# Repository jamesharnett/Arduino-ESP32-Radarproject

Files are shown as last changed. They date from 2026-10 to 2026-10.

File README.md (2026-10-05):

# Arduino ESP32 mmWave Radar Project
-------------------------------------------------------------------------------------------------------
Safety & disclaimer

This is a hobby project, shared as-is for anyone who wants to build their own version.
A few things to know before you do:

LiPo batteries: incorrect wiring, reverse polarity, or physical damage to a
LiPo cell can cause fire. Double-check polarity yourself before powering anything
on, use a charging module rated for the cell you're using, and never leave a
charging LiPo unattended.
RF hardware: the RD-03D and any radio modules in this project operate
according to their respective regulatory approvals (e.g. CE) for their intended
region — verify this applies to your location before use.
No warranty: this repository (firmware, wiring diagrams, enclosures, and this
README) is provided without any warranty, express or implied. Verify every
connection yourself before applying power — don't assume the diagrams here are
free of mistakes.
Use at your own risk: building and operating this project is entirely your
own responsibility. The author assumes no liability for damage, injury, or loss
resulting from building or using this project.

If you spot an error in the docs, wiring, or code, please open an issue — corrections
are welcome.
-------------------------------------------------------------------------------------------------------

A wireless 24GHz mmWave motion tracking system. A standalone radar node reports detected
targets over Wi-Fi to a separate display unit — so the radar and the screen don't have to
be in the same place.

v22 v21

## How it works

The radar module talks to an Arduino GIGA R1 via a Wi-Fi hotspot using a Seeed XIAO
ESP32-S3 as the transmitter. Because the link is wireless, the radar node can be placed
anywhere as a standalone motion detector, independent of where the display sits.

## Features

- Multi-target tracking (up to 3 people simultaneously, RD-03D built-in algorithm)
- 8 m rated detection range (expect 5–7 m indoors)
- Live radar-style visualization on the GIGA Display Shield
- Distance-reactive tracker sound (passive piezo buzzer, tempo and pitch scale with
  the closest target's distance) — mute toggle built into the touchscreen
- LED battery level indicators on both battery packs
- Battery powered on both ends, USB-C rechargeable

## Known limitations

- The RD-03D is a **Doppler-based** radar — it only detects *moving* targets. People
  standing still are not detected.
- Works best stationary. It can detect people while the sensor itself is moving, but
  accuracy drops significantly.
- Can detect motion through thin doors/walls, but range is severely reduced — a
  consequence of 24GHz wave physics, not a firmware limitation.
- **Boot order matters**: always power on the GIGA R1 first and let it fully initialize
  before powering the radar node. Otherwise the Wi-Fi connection will not be established.

## Bill of materials

| Qty | Part |
|---|---|
| 1 | Arduino GIGA R1 |
| 1 | Arduino GIGA Display Shield |
| 1 | Seeed Studio XIAO ESP32-S3 |
| 1 | RD-03D radar module (Ai-Thinker) |
| 2 | Toggle switch |
| 2 | MT3608 step-up converter |
| 1 | 3.7V LiPo, 1160100 (≥5000mAh) — GIGA side |
| 1 | 3.7V LiPo, 602560 (~1300mAh) — radar side |
| 2 | BW4056 USB-C charging module |
| 1 | Passive piezo buzzer module (VCC/GND/Signal, tracker sound, GIGA side) |
| 2 | Mini Battery Level Indicator, 1S Li-ion — [ElectroPeak BAT-03-086](https://electropeak.com/mini-battery-level-indicator-1s-li-ion), one per LiPo |
| 4 | Magnets |
| — | Wires, M3 heat-set inserts, M3x10mm screws, 3D printer, glue, tape |

## Wiring

circuit diagram v2

**Power (GIGA side):** LiPo (5000mAh) → BW4056 charging module → toggle switch →
step-up converter set to 7–7.5V → GIGA `VIN`. Do not set it to 6V: that is the
bottom of the GIGA's 6–24V input range and the board browns out as the cell
discharges. Alternatively feed 5V into the GIGA's USB-C port from a 5V boost or
power-bank module and skip `VIN` altogether.

**Power (radar side):** LiPo (1300mAh) → BW4056 charging module → toggle switch →
XIAO `BAT+`/`BAT-` (on the back of the board), **directly**. A second branch from
the switched battery rail feeds the step-up converter set to 5V, which powers
**only the RD-03D**.

Never connect the 5V step-up output to `BAT+`: the BAT pads are the cell
terminals of the XIAO's 1S charger (4.2V maximum), and a cell behind a boost
converter cannot be charged by the XIAO. With the cell on the BAT pads the XIAO's
USB-C also charges it (100mA, slow); never charge through the BW4056 and the XIAO
at the same time.

### XIAO ESP32-S3 ↔ RD-03D (transmitter)

| RD-03D pin | XIAO pin | Notes |
|---|---|---|
| TX | D0 (GPIO1) | UART1 RX |
| RX | D1 (GPIO2) | UART1 TX |
| VCC | — | 5V from the step-up converter output (see *Power (radar side)* above), not from the XIAO's `5V` pin |
| GND | GND | |

CAUTION: When charging the battery, set the POWER button to OFF. The same applies when the microcontroller is connected via USB-C. 

Baud rate: 256000. Do **not** use D6/D7 (GPIO43/44) — reserved for USB-Serial (UART0).

Antennas: neither the XIAO ESP32-S3 nor the GIGA R1 WiFi has an on-board antenna.
Plug in the u.FL antenna that ships with each board, and route the XIAO's away from
the LiPo and the magnets, or the Wi-Fi link will only work over a few metres.

### Wi-Fi link
### Arduino Giga R1 ↔ (receiver)
| | Value |
|---|---|
| Mode | GIGA R1 hosts an access point, XIAO connects as client |
| SSID | `RadarNet` |
| Password | `radar12345` |
| UDP port | 4210 |
| GIGA IP | 192.168.3.1 (default of the Arduino Mbed core; the sketch never sets an address and the XIAO uses the DHCP gateway, so nothing depends on this value) |

### Tracker sound (buzzer)

| Buzzer | GIGA R1 |
|---|---|
| VCC | 3V3 (GIGA pins are not 5V tolerant and many 3-pin buzzer modules pull the signal line up to VCC) |
| Signal (I/O) | D9 |
| GND | GND |

Must be a **passive** piezo buzzer, not active — an active buzzer has its own
oscillator and only turns on/off, ignoring the frequency argument the code sends it.

Behavior: silent when no target is detected. Once a target appears, it emits short
(70ms) pings whose repeat rate and pitch both scale with the distance to the closest
detected target — pings speed up and rise in pitch as someone gets closer (900ms /
700Hz at ~8m down to 120ms / 1800Hz at ≤30cm). A mute toggle button is drawn directly
on the touchscreen; tapping it silences the buzzer without affecting the radar
visualization.

### Battery level indicators

Two [ElectroPeak Mini Battery Level Indicator (1S Li-ion)](https://electropeak.com/mini-battery-level-indicator-1s-li-ion)
boards, one per LiPo pack. These are standalone analog modules (built-in comparator,
±1% accuracy) — no microcontroller pin or firmware involved. Wire each board directly
across its own battery's `+`/`-` terminals (in parallel with the existing BW4056 /
step-up wiring, not in series):

| Indicator LEDs lit | Charge level |
|---|---|
| 4 | 100% |
| 3 | 75% |
| 2 | 50% |
| 1 | 25% |

Board size is tiny (5 × 9.5mm) — tuck it wherever it fits in the enclosure near the
battery leads.

## Firmware

Open `Firmware 1.1/rd03d_xiao_s3_sender/rd03d_xiao_s3_sender.ino` and flash it to the
XIAO ESP32-S3, then open `Firmware 1.1/rd03d_giga_receiver/rd03d_giga_receiver.ino` and
flash it to the GIGA R1 — both via Arduino IDE. (The Arduino IDE requires the sketch
folder to carry the sketch's own name, which is why the folders are not suffixed.)

**Board packages:**
- `esp32` by Espressif (3.x) — board "XIAO_ESP32S3", *USB CDC On Boot: Enabled*
- `Arduino Mbed OS GIGA Boards` (4.x) — board "Arduino GIGA R1 WiFi". If the GIGA has never
  run Wi-Fi, flash *File → Examples → STM32H747_System → WiFiFirmwareUpdater* once first.

**Required libraries:**
- `Arduino_GigaDisplay_GFX` (GIGA — display rendering; depends on `Adafruit GFX Library`)
- `Arduino_GigaDisplayTouch` (GIGA — touch input)
- `WiFi` / `WiFiUdp` (both boards, built into their respective cores)

## Enclosures

Four 3D-printable parts are included in `CAD files/` (binary STL; bounding boxes
measured from the files):

| File | Bounding box (mm) | Part |
|---|---|---|
| `CAD files/body display.stl` | 34 × 105 × 113 | display body (GIGA + shield + 1160100 LiPo) |
| `CAD files/top display.stl` | 8 × 85 × 111 | display lid |
| `CAD files/top radarmodule.stl` | 47 × 31 × 87 | radar node body |
| `CAD files/bottom radarmodule.stl` | 47 × 6 × 67 | radar node base plate |

## Build photos (older ones, without the battery indicator and buzzer)

building pictures

## License

MIT — see [LICENSE](LICENSE).

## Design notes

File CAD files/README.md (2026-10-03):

# Enclosures

## v1 parts (original author, print-ready)

Binary STL exports from Autodesk Fusion; bounding boxes measured from the files.
They fit the **Level 1** radar node and the GIGA display.

| File | Bounding box (mm) | Holds |
|---|---|---|
| `body display.stl` | 34 × 105 × 113 | GIGA R1 + Display Shield + 1160100 LiPo |
| `top display.stl` | 8 × 85 × 111 | display lid |
| `top radarmodule.stl` | 47 × 31 × 87 | XIAO + RD-03D + 602560 LiPo |
| `bottom radarmodule.stl` | 47 × 6 × 67 | radar node base plate |

Triangle counts are low (208–1088), so curved features print faceted. The GIGA
board is 101.5 mm long inside a 105 mm body: check the fit in your slicer.

## Level 2 sensor node (DRAFT, unverified)

`level2_sensor_node.scad` is a parametric OpenSCAD model for the radar + LIDAR
node: XIAO ESP32-S3, RD-03D lying horizontally behind a 1.2 mm front window,
MT3608, TP4056/BW4056, a 103450 pouch cell, toggle switch and LED indicator
inside a 78 × 100 × 32 mm box, with the LD19 bolted on top of the lid where it
has a clear 360° view. `level2_sensor_node_base.stl` and `level2_sensor_node_lid.stl`
are rendered from the defaults; `level2_sensor_node_preview.png` shows the assembly.

**It was designed from datasheet dimensions, not from measured parts, and has
never been printed.** Before you commit filament:

1. Measure your modules and put the numbers into the parameters at the top of
   the `.scad` file (`rd03d`, `xiao`, `mt3608`, `tp4056`, `cell`, `switch_d`).
2. The LD19 mounting-hole pattern (`ld19_holes`, four holes on a 22 mm square) is
   a **guess**. Measure the base of your LD19, or print the lid alone first and
   drill to fit.
3. The RD-03D needs a plastic window under 2 mm and no metal within 20 mm; the
   model thins the front wall to `rd03d_window_t` over the module. Keep the cell
   and the switch away from that face.
4. A ≥ 3000 mAh cell (recommended for Level 2 runtime) is larger than the
   103450 pocket; set `cell` and raise `box_d` accordingly.
5. Tape the XIAO's flex antenna under the lid in the marked slot, not next to
   the cell, and plug it in before closing the box.

Render with:

```bash
openscad -D 'part="base"' -o level2_sensor_node_base.stl level2_sensor_node.scad
openscad -D 'part="lid"'  -o level2_sensor_node_lid.stl  level2_sensor_node.scad
```

Open the file in OpenSCAD with `part="assembly"` to see the lid, the LD19
silhouette and the RD-03D position together.

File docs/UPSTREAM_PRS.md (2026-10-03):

# Fixes prepared for the upstream repositories

The audit behind the RadarLink rewrite found defects in the original v1 code
and README. They are prepared as small, independent branches in this fork so
each can be opened as its own pull request against the author's repositories.
The branches are based on `main`, which is identical to the upstream `main`
(commit `c41c875`).

| Branch in this fork | Target repository | Files | Summary |
|---|---|---|---|
| `fix/readme-wiring-and-facts` | `Stevee87/Arduino-ESP32-Radarproject` | `README.md` | 5 V boost into XIAO `BAT+` corrected (cell on BAT pads, boost feeds only the RD-03D); GIGA VIN 7–7.5 V or USB-C instead of 6 V; antennas; buzzer on 3V3; AP address 192.168.3.1; firmware paths; real enclosure files and sizes; BW4056 naming; board packages and Adafruit GFX dependency; duplicate caution; typo |
| `fix/wifiudp-include-case` | `Stevee87/Arduino-ESP32-Radarproject` | receiver `.ino` | `#include <WiFiUDP.h>` → `<WiFiUdp.h>`; the sketch did not compile on Linux |
| `fix/giga-receiver-robustness` | `Stevee87/Arduino-ESP32-Radarproject` | receiver `.ino` | check `WiFi.beginAP()` and show the failure on screen; drain all queued UDP datagrams per loop instead of one; `fb[12]` overflow → `fb[16]`; "R4" labels renamed |
| `fix/xiao-transmitter-nonblocking` | `Stevee87/Arduino-ESP32-Radarproject` | transmitter `.ino` | non-blocking Wi-Fi connect with retry instead of a 20 s block and `ESP.restart()`; the 650 ms radar re-configuration every 60 s turned into a timed step sequence; clustering keeps the speed with the larger magnitude |
| `fix/receiver-packet-format` in `jamesharnett/Radar-project-Uconsole` | `Stevee87/Radar-project-Uconsole` | `Firmware/uconsole_radar_receiver.py` | the Python receiver unpacked 29 of the 32 packet bytes and corrupted targets 2 and 3 (`"hhhB"` → `"hhhBx"` per target). The same change also exists as a `git am` patch on this fork's `fix/radar-project-uconsole-struct-format` branch, which is now redundant |

Each code branch was compiled for its board (esp32 core 3.3.12 for the XIAO,
Arduino Mbed OS GIGA Boards 4.6.0 for the GIGA) before it was pushed. The
receiver robustness branch only builds on Linux once the include-name fix is
also merged; the two are kept separate so the one-line fix can land on its own.

## Opening the pull requests

From the fork on GitHub: *Pull requests → New → compare across forks*, base
`Stevee87/Arduino-ESP32-Radarproject:main`, head `<fork>:<branch>`. The commit
message of each branch is written to serve as the PR description.

For the `Radar-project-Uconsole` fix, open the pull request from
`jamesharnett/Radar-project-Uconsole:fix/receiver-packet-format` against
`Stevee87/Radar-project-Uconsole:main`.

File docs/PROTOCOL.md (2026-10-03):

# RadarLink v1 — UDP wire protocol

Every node in the system speaks one protocol on one UDP port. The sensor node
(ESP32-S3 with the RD-03D radar and the optional LD19 LIDAR) is the Wi-Fi access
point and the only sender of measurement data. Receivers (the Arduino GIGA R1
display and the uConsole viewer) announce themselves with a `HELLO` once per
second and the sensor node unicasts every data packet to each receiver that has
said hello within the last five seconds. There is no broadcast: the original
author measured unreliable delivery of broadcast frames under LIDAR load, and
unicast frames are acknowledged and retransmitted by the Wi-Fi layer.

The canonical machine-readable definition is
`Firmware/sensor_node_esp32s3/radar_protocol.h`. The copy in
`Firmware/giga_display/` must stay byte-identical (`tools/check_protocol_sync.py`),
and `uconsole/radar_protocol.py` is the Python mirror, verified against the C
header by `uconsole/tests/test_protocol.py`.

## Conventions

* UDP port **4210** for everything, in both directions.
* All multi-byte integers are **little-endian**.
* Every field is written byte by byte. No struct is ever sent raw, so compiler
  padding can never change the format (the v1 firmware had exactly that trap:
  an unpacked 7-byte struct became 8 bytes on the wire and a third-party decoder
  written for 29 bytes misread targets 2 and 3).
* No datagram is longer than **508 bytes**, because that is the receive buffer
  of the Arduino Mbed `WiFiUDP` implementation on the GIGA R1. Anything longer
  would be truncated there without an error.
* Receivers accept data only from the sensor node's address (the Wi-Fi gateway)
  and drop packets whose sequence number is not newer than the last one seen for
  that type. Wi-Fi security is WPA2 with the pre-shared key in `config.h`; change
  it before deploying.

## Common header (8 bytes)

| Offset | Size | Field | Value |
|---:|-----:|---|---|
| 0 | 4 | `magic` | `0x314C4452`, the ASCII bytes `52 44 4C 31` ("RDL1") |
| 4 | 1 | `type` | see below |
| 5 | 1 | `version` | `1` |
| 6 | 2 | `seq` | per-type sequence counter of the sender, wraps at 65535 |

| Type | Name | Direction | Rate |
|-----:|---|---|---|
| `0x01` | `RADAR`  | sensor node → receivers | one per RD-03D frame, about 10 to 20 per second |
| `0x02` | `LIDAR`  | sensor node → receivers | about 47 per second with the LD19 at 10 Hz |
| `0x03` | `STATUS` | sensor node → receivers | 1 per second |
| `0x10` | `HELLO`  | receiver → sensor node  | 1 per second |

## RADAR (type 0x01), 36 bytes

| Offset | Size | Field |
|---:|-----:|---|
| 8  | 4 | `frame_count`, RD-03D frames parsed since boot |
| 12 | 24 | three target slots of 8 bytes each (see below) |

Each slot:

| Offset in slot | Size | Field |
|---:|-----:|---|
| 0 | 2 | `x_mm`, `int16`, lateral position, positive to the right of the radar's forward axis |
| 2 | 2 | `y_mm`, `int16`, forward distance |
| 4 | 2 | `speed_cm_s`, `int16`, radial speed with the RD-03D's sign convention |
| 6 | 1 | `valid`, `1` if the slot holds a target, otherwise `0` and the other fields are `0` |
| 7 | 1 | reserved, `0` |

The slot index is stable while the RD-03D keeps tracking the same person, which
is why receivers colour targets by slot. The sensor node has already applied the
range gate (100 mm to 8000 mm), the sentinel-speed filter (`0`, `±248`, `±256`
cm/s are noise in the RD-03D firmware) and the clustering of two returns closer
than 1 m into one target.

## LIDAR (type 0x02), 12 + 5·N bytes, N ≤ 96

| Offset | Size | Field |
|---:|-----:|---|
| 8  | 2 | `scan_speed_deg_s`, motor speed reported by the LD19 |
| 10 | 1 | `count` N, number of points that follow, at most 96 |
| 11 | 1 | `flags`, reserved, `0` |
| 12 | 5·N | points |

Each point:

| Offset in point | Size | Field |
|---:|-----:|---|
| 0 | 2 | `angle_cdeg`, `uint16`, 0 to 35999, hundredths of a degree, increasing clockwise seen from above, in the LD19's own reference |
| 2 | 2 | `dist_mm`, `uint16`, never `0` (points without a return are dropped at the sensor node) |
| 4 | 1 | `intensity` |

A packet carries up to eight LD19 frames of twelve points. The receivers apply
the mounting offset `LIDAR_ANGLE_OFFSET_DEG` from their own configuration, so
the sensor node never needs recalibrating for a different display.

## STATUS (type 0x03), 32 bytes

| Offset | Size | Field |
|---:|-----:|---|
| 8  | 4 | `uptime_ms` |
| 12 | 2 | `radar_fps`, RD-03D frames parsed in the last second |
| 14 | 2 | `lidar_fps`, LD19 frames parsed in the last second |
| 16 | 2 | `lidar_pps`, LIDAR points sent in the last second |
| 18 | 1 | `subscribers`, receivers currently registered |
| 19 | 1 | `flags`: bit 0 radar frames seen in the last second, bit 1 lidar frames seen, bit 2 radar multi-target mode configured, bit 3 firmware built with LIDAR support |
| 20 | 4 | `radar_bad_frames`, cumulative frames with a bad tail |
| 24 | 4 | `lidar_crc_errors`, cumulative |
| 28 | 4 | reserved |

Receivers show these numbers in their HUD. They make the difference between
"the radar is not wired" and "the Wi-Fi link is down" visible at a glance.

## HELLO (type 0x10), 12 bytes

| Offset | Size | Field |
|---:|-----:|---|
| 8  | 1 | `receiver_kind`: `1` GIGA display, `2` uConsole, `3` other |
| 9  | 1 | `wants` bitmask: bit 0 radar, bit 1 lidar, bit 2 status |
| 10 | 2 | reserved |

The sensor node records the source address and port of each `HELLO` and sends
to that address until no `HELLO` has arrived for 5 s. Up to four receivers are
served at once. A receiver that is only interested in radar can clear bit 1 and
save the LIDAR bandwidth.

## Timing constants

| Constant | Value | Meaning |
|---|---:|---|
| `RL_HELLO_INTERVAL_MS` | 1000 | receivers send `HELLO` this often |
| `RL_SUBSCRIBER_TIMEOUT_MS` | 5000 | sensor node forgets a silent receiver |
| `RL_LINK_TIMEOUT_MS` | 3000 | receiver declares the link dead and clears the screen |

## Worked example

A radar packet with one target at x = −782 mm, y = 1713 mm, −16 cm/s in slot 0,
sequence 7, frame 1234:

```
52 44 4C 31  01 01  07 00   | magic "RDL1", type RADAR, version 1, seq 7
D2 04 00 00                  | frame_count 1234
F2 FC  B1 06  F0 FF  01 00   | slot 0: x=-782 y=1713 speed=-16 valid=1 pad
00 00  00 00  00 00  00 00   | slot 1 empty
00 00  00 00  00 00  00 00   | slot 2 empty
```

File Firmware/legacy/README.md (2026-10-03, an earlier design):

# Legacy v1 firmware (reference only)

These are the original two sketches by Sudo_solder, kept so the first-generation
build (GIGA R1 as access point, XIAO as client, 32-byte packed-struct packets on
UDP 4210) can still be flashed and compared against. They are **not** compatible
with the current sensor node, display or uConsole viewer, which use the RadarLink
protocol in `docs/PROTOCOL.md`.

The only change made here is the `WiFiUdp.h` include name in the receiver, which
the Mbed core ships in that case and which failed to compile on Linux as `WiFiUDP.h`.

Known issues in this code, found in the audit that led to the rewrite:

* the transmitter unicasts to the Wi-Fi gateway only, so a second viewer gets nothing;
* the GIGA reads one UDP datagram per loop while each dot erase re-walks the whole
  sector with ~125k trig calls, so the display lags under load and never catches up;
* a blocking 20 s Wi-Fi connect followed by `ESP.restart()` reboot-loops the XIAO;
* a 650 ms blocking re-configuration of the radar every 60 s;
* `WiFi.beginAP()` failure is never checked, so a missing Wi-Fi firmware looks like a boot-order problem;
* the README's `192.168.4.1` is wrong for this core (the AP is `192.168.3.1`);
* `char fb[12]` overflows after 100 million frames (about 116 days).

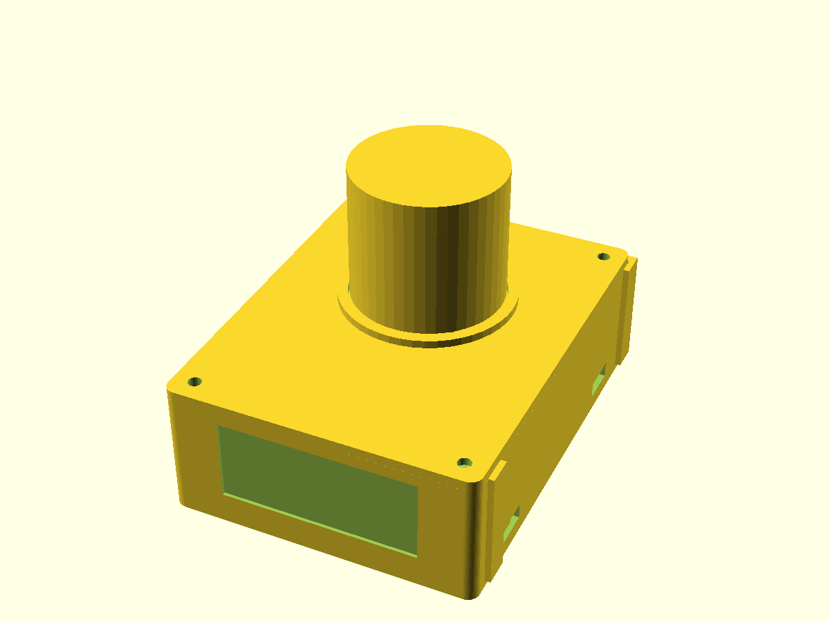
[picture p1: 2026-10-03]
CAD files/level2_sensor_node_preview.png

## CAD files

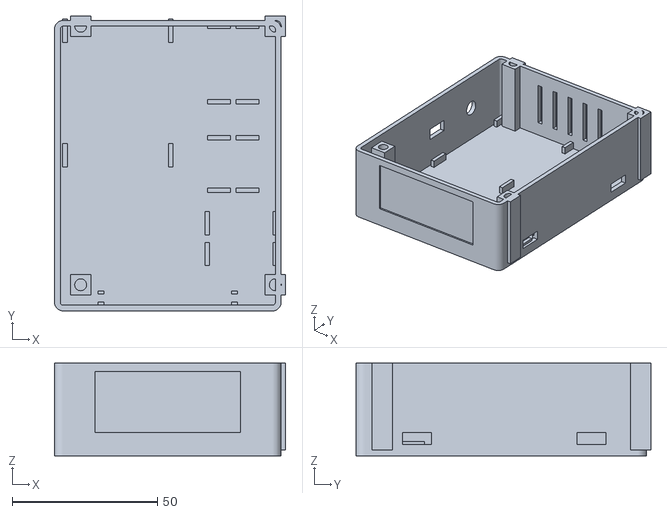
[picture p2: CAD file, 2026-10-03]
CAD files/level2_sensor_node_base.stl
79.5 x 101.5 x 32.0

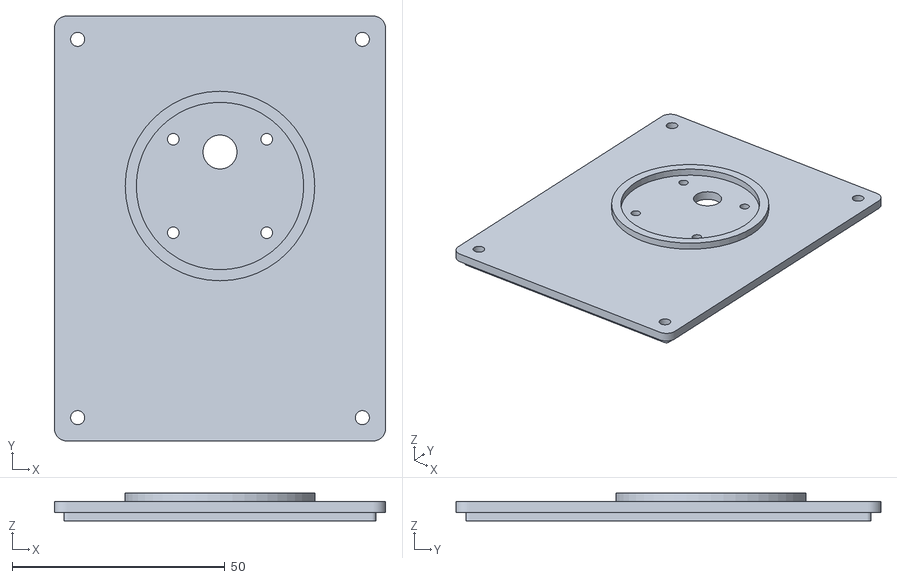
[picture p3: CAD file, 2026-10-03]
CAD files/level2_sensor_node_lid.stl
78.0 x 100.0 x 6.49

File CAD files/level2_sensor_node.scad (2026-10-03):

// level2_sensor_node.scad — RadarLink Level 2 sensor node enclosure (DRAFT, unverified)
//
// Holds: Seeed XIAO ESP32-S3, Ai-Thinker RD-03D (horizontal, behind a thin front
// window), MT3608 boost module, TP4056/BW4056 USB-C charger, a pouch cell, a
// toggle switch and a 1S LED indicator, with the LDROBOT LD19 LIDAR mounted on
// top of the lid where it has a clear 360-degree view.
//
// THIS IS A DRAFT DESIGNED FROM DATASHEET NUMBERS, NOT FROM MEASURED PARTS.
// Before printing in earnest: measure every module you actually own and put the
// numbers into the parameters below, print only the lid first to check the LD19
// hole pattern (ld19_holes is a guess), and check the RD-03D window thickness
// (keep it under 2 mm, no metal within 20 mm of the module's face).
//
// Render:  openscad -D 'part="base"' -o level2_base.stl level2_sensor_node.scad
//          openscad -D 'part="lid"'  -o level2_lid.stl  level2_sensor_node.scad
// Preview: part="assembly"
//
// Axes: x = width (left/right), y = depth (front at -y), z = up. The RD-03D
// looks towards -y; mount the LD19 so its connector points to +y, then set the
// receivers' LIDAR_ANGLE_OFFSET_DEG from the calibration in docs/TESTING.md.
//
// SPDX-License-Identifier: MIT

part = "assembly";          // "base" | "lid" | "assembly"

/* ------------------------------------------------------------ parameters */
wall      = 2.0;            // side wall thickness
floor_t   = 2.0;
lid_t     = 2.5;
corner_r  = 3.0;
clear     = 0.4;            // clearance added around parts

// components (mm) — MEASURE YOURS
rd03d     = [44.0, 2.0, 15.0];  // PCB width, thickness (with antenna face), height; mounted horizontally
rd03d_window_t = 1.2;           // front window thickness in front of the radar
xiao      = [21.0, 17.8, 4.0];  // PCB x, y, height incl. components (USB-C adds 1.3 mm on one side)
mt3608    = [36.0, 17.0, 12.0]; // boost module incl. trimmer
tp4056    = [28.0, 17.0, 6.0];  // USB-C charger module
cell      = [34.0, 50.0, 10.5]; // pouch cell; 103450 = 2000 mAh. 3000 mAh (e.g. 606090: 60x90x6) needs box_d >= 110
switch_d  = 6.2;                // toggle switch hole
indicator = [9.5, 5.0];         // 1S 4-LED indicator window (w, h)
ld19_dia  = 38.6;               // LD19 body diameter
ld19_h    = 34.8;               // LD19 height above its base
ld19_holes = [[-11.0, -11.0], [11.0, -11.0], [-11.0, 11.0], [11.0, 11.0]];  // GUESS: measure the LD19 base
ld19_hole_d = 2.7;              // M2.5 clearance
ld19_cable_d = 8.0;

// layout
box_w = 74;                     // internal width
box_d = 96;                     // internal depth
box_h = 30;                     // internal height (components lie flat)
insert_d = 4.1;                 // heat-set insert hole for M3
insert_h = 6.0;
post     = 7.0;                 // corner post size

$fn = 48;

/* --------------------------------------------------------------- helpers */
module rrect(w, d, h, r) {
    hull() for (sx = [-1, 1], sy = [-1, 1])
        translate([sx * (w / 2 - r), sy * (d / 2 - r), 0]) cylinder(r = r, h = h);
}

module pocket(size, z = floor_t, rail = 1.6, rail_h = 3.0) {
    // four short rails that locate a PCB of `size` on the floor without screws
    s = [size[0] + 2 * clear, size[1] + 2 * clear];
    for (sx = [-1, 1], sy = [-1, 1])
        translate([sx * (s[0] / 2 + rail / 2), sy * (s[1] / 2 - 4), z])
            cube([rail, 8, rail_h], center = false);
}

ow = box_w + 2 * wall;
od = box_d + 2 * wall;
oh = box_h + floor_t;

/* ------------------------------------------------------------------ base */
module base() {
    difference() {
        union() {
            rrect(ow, od, oh, corner_r);
        }
        // cavity
        translate([0, 0, floor_t]) rrect(box_w, box_d, box_h + 1, corner_r - wall > 0.5 ? corner_r - wall : 0.5);
        // RD-03D window: thin the front wall to rd03d_window_t over the module face
        translate([-(rd03d[0] + 6) / 2, -od / 2 - 0.01, floor_t + 6])
            cube([rd03d[0] + 6, wall - rd03d_window_t + 0.01, rd03d[2] + 6]);
        // TP4056 USB-C on the right wall, near the back
        translate([ow / 2 - wall - 0.01, box_d / 2 - 12 - 10, floor_t + 2]) cube([wall + 0.02, 10, 4]);
        // XIAO USB-C on the right wall, near the front (programming)
        translate([ow / 2 - wall - 0.01, -box_d / 2 + 14, floor_t + 2]) cube([wall + 0.02, 10, 4]);
        // toggle switch on the left wall
        translate([-ow / 2 - 0.01, box_d / 2 - 20, floor_t + box_h / 2]) rotate([0, 90, 0]) cylinder(d = switch_d, h = wall + 0.02);
        // indicator window on the left wall
        translate([-ow / 2 - 0.01, 0, floor_t + box_h / 2 - indicator[1] / 2]) cube([wall + 0.02, indicator[0], indicator[1]]);
        // vents on the back wall
        for (i = [-2 : 2]) translate([i * 8 - 1, od / 2 - wall - 0.01, floor_t + 6]) cube([2, wall + 0.02, box_h - 12]);
    }
    // corner posts with heat-set insert holes
    for (sx = [-1, 1], sy = [-1, 1]) difference() {
        translate([sx * (box_w / 2 - post / 2), sy * (box_d / 2 - post / 2), floor_t]) cube([post, post, box_h], center = false);
        translate([sx * (box_w / 2 - post / 2) + post / 2, sy * (box_d / 2 - post / 2) + post / 2, floor_t + box_h - insert_h])
            cylinder(d = insert_d, h = insert_h + 0.01);
    }
    // RD-03D cradle: two slots the module slides into, face against the window
    for (sx = [-1, 1]) translate([sx * (rd03d[0] / 2 + 1.0) - 1.0, -box_d / 2, floor_t])
        difference() {
            cube([2.0, rd03d[1] + 2 * clear + 2, rd03d[2] + 8]);
            translate([-0.01, 1.0, 2]) cube([2.02, rd03d[1] + 2 * clear, rd03d[2] + 7]);
        }
    // component pockets (flat on the floor)
    translate([-box_w / 2 + cell[0] / 2 + 2, box_d / 2 - cell[1] / 2 - 2, 0]) pocket(cell);
    translate([box_w / 2 - mt3608[1] / 2 - 2, box_d / 2 - mt3608[0] / 2 - 2, 0]) rotate([0, 0, 90]) pocket(mt3608);
    translate([box_w / 2 - tp4056[1] / 2 - 2, 6, 0]) rotate([0, 0, 90]) pocket(tp4056);
    translate([box_w / 2 - xiao[0] / 2 - 2, -box_d / 2 + xiao[1] / 2 + 10, 0]) pocket(xiao);
}

/* ------------------------------------------------------------------- lid */
module lid() {
    difference() {
        union() {
            rrect(ow, od, lid_t, corner_r);
            // inner lip
            translate([0, 0, -2]) difference() {
                rrect(box_w - 0.6, box_d - 0.6, 2.01, corner_r - wall > 0.5 ? corner_r - wall : 0.5);
                translate([0, 0, -0.01]) rrect(box_w - 0.6 - 2 * 1.6, box_d - 0.6 - 2 * 1.6, 2.03, 1);
            }
            // LD19 seat ring
            translate([0, 10, lid_t - 0.01]) difference() {
                cylinder(d = ld19_dia + 6, h = 2);
                translate([0, 0, -0.01]) cylinder(d = ld19_dia + 2 * clear, h = 2.02);
            }
        }
        // lid screws into the corner posts
        for (sx = [-1, 1], sy = [-1, 1])
            translate([sx * (box_w / 2 - post / 2), sy * (box_d / 2 - post / 2), -3]) cylinder(d = 3.3, h = lid_t + 6);
        // LD19 mounting holes and cable pass-through
        for (h = ld19_holes) translate([h[0], 10 + h[1], -3]) cylinder(d = ld19_hole_d, h = lid_t + 6);
        translate([0, 10 + 8, -3]) cylinder(d = ld19_cable_d, h = lid_t + 6);
        // antenna slot: the XIAO's flex antenna is taped under the lid, front-right, away from the cell
        translate([box_w / 2 - 14, -box_d / 2 + 4, -0.01]) cube([12, 30, 0.6]);
    }
}

module ld19_ghost() {
    color("silver", 0.4) translate([0, 10, oh + lid_t + 2]) cylinder(d = ld19_dia, h = ld19_h);
}

/* --------------------------------------------------------------- output */
if (part == "base") base();
else if (part == "lid") translate([0, 0, 0]) lid();
else {
    base();
    translate([0, 0, oh + 0.01]) lid();
    ld19_ghost();
    color("green", 0.5) translate([-rd03d[0] / 2, -box_d / 2 + 1.5, floor_t + 2]) cube(rd03d);
}

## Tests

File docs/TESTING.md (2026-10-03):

# Bring-up, testing and calibration

Work through this in order the first time. Every stage has an expected output,
so a radar wiring fault, a LIDAR fault and a Wi-Fi fault each look different.

## 0. Bench test the software without hardware

```bash
cd uconsole
python3 -m unittest discover -s tests            # 19 tests: protocol bytes vs the C header, state logic
python3 fake_sensor_node.py &                    # simulated sensor node on UDP 4210
python3 radar_viewer.py --node 127.0.0.1 --windowed
```

You should see a 6 × 4 m rectangular room outline with a gap (a "doorway") and
one or two walkers in the radar sector, `DATA OK` in the HUD and roughly
`rx 70/s`. Quit with ESC, stop the fake node with `kill %1`.

Parser tests for the firmware run on your PC too:

```bash
g++ -std=c++11 -Wall -Wextra -Werror -I Firmware/sensor_node_esp32s3 Firmware/tests/host/test_parsers.cpp -o /tmp/t && /tmp/t
```

## 1. Sensor node on USB power, radar only

Battery switch **off**, `ENABLE_LIDAR 0` for this step if you like, XIAO on USB,
serial monitor at 115200 baud. Expected:

```
RadarLink sensor node — RD-03D + LD19
radar UART1 rx=1 tx=2 @256000 | lidar UART2 rx=3 tx=4 @230400
[wifi] AP "RadarSystem" up on channel 6, IP 192.168.4.1, UDP port 4210
[boot] ready; waiting for receivers to say HELLO
[radar] multi-target mode configured
[stat] up=2s ap=up sta=0 subs=0 | radar fps=20 bytes=1234 bad=0 cfg=1 reconf=0 | lidar fps=0 pps=0 bytes=0 crc=0 speed=0 | heap=...
```

With the RD-03D powered from the boost converter (trimmed to 5.0 V first):

| What you see | Meaning |
|---|---|
| `radar fps=10..20 bad=0`, `bytes` growing | radar wired and configured. Normal. |
| `bytes` growing, `fps=0`, `bad` growing | framing wrong: wrong baud (must be 256000) or a swapped TX/RX pair that still receives garbage |
| `bytes=0` | no data at all: RD-03D not powered (needs 5 V), TX not on D0, or GND missing |
| `reconf` incrementing every 5 s | radar silent for 5 s each time; the node re-sends the mode command. Check the 5 V rail with a meter under load |

The LED blinks briefly every 0.5 s while no receiver is subscribed and every
2 s once one is.

## 2. Add the LD19

Connect the LD19 (Tx → D2, P5V from the boost, GND common, PWM open). The motor
spins up within a second. Expected in `[stat]`:

```
lidar fps=370..380 pps=3500..4500 crc=0 speed=3500..3700
```

| What you see | Meaning |
|---|---|
| `fps≈375 crc=0` | good. `pps` is lower than 4500 when part of the room is beyond 12 m or absorbs the laser |
| `bytes` growing, `fps=0`, `crc` growing | wrong baud (must be 230400) or noise on the line |
| `bytes=0` | LD19 TX not on D2, or no power. Listen for the motor |
| `crc` growing slowly with `fps≈370` | occasional corrupt frames: supply ripple or a long unshielded lead. Add the 220 µF + 10 µF at the sensors |

## 3. GIGA display

Serial monitor at 115200. Expected:

```
RadarLink GIGA display starting
[wifi] connecting to RadarSystem
[wifi] connected, IP 192.168.4.2, sensor node 192.168.4.1, RSSI -45
[stat] link=up data=ok rx/s=70 total=140 drop=0 foreign=0 fps=15 | node radar_fps=20 lidar_fps=375 subs=1
```

The screen shows the plot once joined; `WIFI OK`, `DATA OK` and the node's
counters appear in the top-left HUD. On the sensor node you will see
`[subs] + 192.168.4.2:4210 kind=1 wants=0x07 (1 total)` and `[wifi] station joined`.

| What you see | Meaning |
|---|---|
| `connect failed, status 4` repeating, screen says "last attempt failed (code 4)" | the Mbed core returns 4 (`WL_CONNECT_FAILED`) both when the SSID is not seen in its scan and when the join is refused: node not powered or still booting, out of range, antenna missing, or wrong SSID/password |
| `connect failed, status 0` | no Wi-Fi module answered: run the WiFiFirmwareUpdater example |
| each attempt takes a minute | the join worked but DHCP did not answer (60 s core timeout): power-cycle the node |
| "Failed to mount the filesystem containing the WiFi firmware" on serial | run *File → Examples → STM32H747_System → WiFiFirmwareUpdater* once |
| link up, `data=none`, HUD "waiting for sensor node" | packets not arriving: wrong `RECEIVER_WANTS`, or the node shows `subs=0` (HELLO not received: both on the same channel? check node log) |
| `drop` counting up | packets arriving out of order; harmless unless large |
| `fps` well below 15 | the display is CPU bound; disable LIDAR drawing (touch LIDAR OFF) to confirm |

## 4. uConsole

```bash
nmcli dev wifi connect RadarSystem password '...'
python3 radar_viewer.py --windowed
```

Console output every 2 s:

```
[net] listening on UDP 4210, sensor node 192.168.4.1:4210
[stat] data=ok rx/s=70 total=1400 drop=0 foreign=0 fps=30 | node radar_fps=20 lidar_fps=375 subs=2
```

`subs=2` confirms both displays are being served at once. If `data=none`
although the GIGA works: check that the viewer's node address is the Wi-Fi
gateway (`ip route`), that Wi-Fi power save is off (`iw dev wlan0 get power_save`),
and that no firewall blocks UDP 4210 inbound (`sudo ufw allow 4210/udp`).

## 5. Battery test

Switch to battery on each node, repeat stages 1–4, then leave everything running
for an hour and watch `reconf`, `crc` and `drop`. Rising `reconf` or `crc` only
on battery points at the boost converter: add capacitance or lower its load.

## 6. Boot order

Power the displays first, then the node; then the node first, then the displays;
then power-cycle the node while the displays run. All three must recover within
about 15 s: the displays retry every 3 s, drop a dead link after 15 s of silence
and the node accepts a `HELLO` at any time.

## Calibration

### LIDAR rotation offset

1. Stand 2 m in front of the node, in line with the radar's forward axis (the
   radar dot should sit on the vertical centre line at the top).
2. Look where the matching LIDAR return (a short arc at 2 m) appears. Read its
   angle clockwise from the top of the plot, e.g. 90° if it is at 3 o'clock.
3. Subtract: set `LIDAR_ANGLE_OFFSET_DEG` (GIGA `config.h`) and `--offset`
   (viewer, or edit `LIDAR_ANGLE_OFFSET_DEG` in `radar_viewer.py`) to minus that
   angle (−90 in the example). Re-flash / restart and confirm the arc moved up.
4. If the room appears mirrored (left/right swapped) set `LIDAR_CLOCKWISE 0`.

### Radar left/right

Walk from the centre line to your left. The dot must move left on both displays.
If it moves right, the RD-03D is mounted rotated 180°: turn it, or set
`RADAR_MIRROR_X 1` in the GIGA `config.h` (the viewer has the same constant).

### Radar range check

Walk away along the centre line. Targets should track to 6–8 m indoors. Loss
before 5 m usually means the module faces plastic thicker than 2 mm, a metal
object within 20 cm, or supply ripple.

## 7. Intrusion detection

Bench first, with the simulator (one terminal each):

```bash
python3 fake_sensor_node.py --quiet-room --intruder-after 20 --intruder-stay 15
python3 radar_viewer.py --node 127.0.0.1 --windowed --learn 10 --baseline /tmp/b.json --alert-log /tmp/a.log
```

Expected: `[detect] learning ...` for 10 s, `baseline learned: ~680 reliable, ~40 open`,
`[detect] ARMED`, then at about 20 s `[alert] START #1 radar ...` as the walker
enters the doorway, upgraded to `fused ... conf 0.95` within a second as the
LIDAR confirms the body, and `[alert] END #1` a second after the walker leaves.
One person should produce one alert id; `/tmp/a.log` holds the CSV rows.

On hardware:

1. Leave the room, or stand still well outside the LIDAR's view, and press `B`
   (or start with `--learn 10`). Learning takes 10 s; the HUD counts down.
2. The HUD then shows `disarmed  baseline N buckets`. N should be close to the
   number of directions with a wall or furniture in range; a value under ~300
   means the LIDAR saw mostly nothing (range, glass, black walls) and the
   detector will only have the radar to work with.
3. Press `A`. Walk in: expect `radar` within a second of moving in the radar
   sector, `fused` once you are inside the LIDAR's view for half a second, red
   arc on the body, siren unless muted.
4. Place a box and leave: a `lidar` alert appears after 0.5 s and stays until
   the box is removed (plus a 1 s hold).
5. False alarms: a curtain or plant moving in a draught shows as flickering
   `lidar` alerts in one direction. Raise `--delta-mm` (default 300) or
   `--dwell-s` (default 0.5), or re-learn the baseline with the window closed.
   Pets below the LIDAR plane are invisible to it but may trigger `radar`.

The baseline is saved to `baseline.json` in the working directory and loaded on
the next start; re-learn after moving furniture.

## 8. Relay and web view

Bench test with the simulator, three terminals:

```bash
python3 fake_sensor_node.py --quiet-room --intruder-after 30
python3 radar_relay.py --node 127.0.0.1 --serve-port 4211 --web 8080 --learn 10 --baseline /tmp/b.json
python3 radar_viewer.py --node 127.0.0.1 --node-port 4211 --windowed      # a "remote" viewer via the relay
```

(`--serve-port 4211` only because the fake node already holds 4210 on this
machine; on the uConsole the relay uses 4210 and remote viewers need no port
option.) Expected: the relay logs `+ remote viewer 127.0.0.1:...`, the viewer
shows `DATA OK` with the same scene, `http://localhost:8080/` draws it in the
browser, and the alert at ~30 s appears in the relay log, in the viewer's own
detector if armed, and on the web page.

On the uConsole: install the service (`uconsole/radar-relay.service`), check
`journalctl -u radar-relay -f` for `[stat] data=ok`, then from a phone on the
same Wi-Fi open `http://<uConsole IP>:8080/`. For off-site access install
Tailscale, `tailscale up`, and use the tailnet address instead; test the web
page from mobile data with Wi-Fi off on the phone.

## Recording a session

```bash
python3 radar_viewer.py --record walk1.rdl     # or press R while running
python3 radar_viewer.py --replay walk1.rdl --windowed --loop --speed 2
```

Recordings are raw datagrams with timestamps; a 10-minute session is about
15 MB. Attach one to an issue if you report a decoding or display problem.

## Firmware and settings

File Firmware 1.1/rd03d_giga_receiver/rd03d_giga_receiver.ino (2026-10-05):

/*
 * RD-03D Radar Display — Arduino Giga R1
 * Empfängt UDP-Pakete vom Single-Sensor-Sender und zeigt bis zu 3 Targets
 * auf dem Display (ein RD-03D, 120° Sichtfeld).
 *
 * NETZWERK:
 *   Giga R1 ist Hotspot: SSID "RadarNet", PW "radar12345"
 *   Eigene IP: 192.168.3.1 (Standard des Arduino-Mbed-Cores; der XIAO nutzt die Gateway-IP)
 *   UDP Port: 4210
 */

#include <WiFi.h>
#include <WiFiUdp.h>
#include "Arduino_GigaDisplay_GFX.h"
#include "Arduino_GigaDisplayTouch.h"

// ── Netzwerk ──
const char*    AP_SSID = "RadarNet";
const char*    AP_PASS = "radar12345";
const uint16_t UDP_PORT = 4210;

// ── Display ──
#define SCREEN_W    800
#define SCREEN_H    480
#define RADAR_CX    400
#define RADAR_CY    480
#define RADAR_R     440
#define MAX_DIST_MM 8000.0f
#define SECTOR_HALF 60.0f
#define MAX_TARGETS 3
#define MOVE_THRESH_MM 15.0f

// ── Ein Sensor, 120° FOV, zentriert auf die Gerätefront (0°) ──
#define NUM_SECTORS 1
const float SECTOR_CENTERS[NUM_SECTORS] = {0.0f};

// ── Buzzer (Tracker-Sound) ──
#define BUZZER_PIN     9      // passiver Piezo-Buzzer, KEIN aktiver Buzzer!

// Jeder Ping besteht aus 2 Stufen: kurzer heller "Klick" (Attack) direkt
// gefolgt vom eigentlichen Ton — kommt dem hellen, sonarartigen Charakter
// des Vorbilds näher als ein einzelner flacher Ton.
// Jeder Ping ist ein kurzer 3-stufiger AUFWÄRTS-Sweep (tief -> mittel ->
// Zielfrequenz), statt eines einzelnen flachen Tons — klingt nach einem
// ansteigenden Sonar-Ping statt einem Klick.
const uint16_t PING_STAGE1_MS = 26;
const uint16_t PING_STAGE2_MS = 24;
const uint16_t PING_STAGE3_MS = 30;
#define BEEP_DUR_MS  (PING_STAGE1_MS + PING_STAGE2_MS + PING_STAGE3_MS)   // Gesamtlänge eines Pings

const float    BEEP_DIST_MIN      = 300.0f;   // mm — ab hier schnellster/höchster Ping
const float    BEEP_DIST_MAX      = 8000.0f;  // mm — ab hier langsamster/tiefster Ping
const uint16_t BEEP_INTERVAL_MIN  = 120;      // ms Pause zwischen Pings bei minimaler Distanz
const uint16_t BEEP_INTERVAL_MAX  = 900;      // ms Pause zwischen Pings bei maximaler Distanz
const uint16_t BEEP_FREQ_MIN      = 700;      // Hz — Tonhöhe weit weg (Kompromiss: lauter, aber unterhalb des schrillen Bereichs)
const uint16_t BEEP_FREQ_MAX      = 1400;     // Hz — Tonhöhe nah dran

// ── Mute-Button (Touch) ──
#define BTN_X 660
#define BTN_Y 400
#define BTN_W 130
#define BTN_H 40
bool buzzerMuted = false;

// ── Range-HUD-Position (Basis der Radar-Kuppel, überdeckt Ursprung) ──
#define RANGE_HUD_W 140
#define RANGE_HUD_H 40
#define RANGE_HUD_X (RADAR_CX - RANGE_HUD_W/2)
#define RANGE_HUD_Y (RADAR_CY - RANGE_HUD_H)

// ── Farben ──
#define C_BG    0x0000
#define C_GREEN 0x07E0
#define C_GDIM  0x02E0
#define C_RED   0xF800
#define C_AMBER 0xFD20
#define C_CYAN  0x07FF
#define C_WHITE 0xFFFF

GigaDisplay_GFX          display;
Arduino_GigaDisplayTouch touch;
WiFiUDP                  udp;

struct Target {
  int16_t x;
  int16_t y;
  int16_t spd;
  uint8_t valid;
};

struct __attribute__((packed)) UdpPacket {
  uint32_t magic;
  uint32_t frameCount;
  Target   targets[MAX_TARGETS];
};

struct DisplayTarget {
  float x, y, spd;
  bool  valid;
};

struct DotState {
  int16_t cx, cy, bx, by, bw, bh;
  bool active;
};

DisplayTarget targets[MAX_TARGETS];
DisplayTarget lastDrawn[MAX_TARGETS];
DotState      dots[MAX_TARGETS];

// ── Ghost-Filter: Ziel, das sich 2s lang nicht (spürbar) bewegt, gilt als ──
// Störung/Geisterziel (der RD-03D erkennt stehende Personen ohnehin nicht
// zuverlässig — ein "Ziel", das sich gar nicht bewegt, ist verdächtig) und
// wird ausgeblendet, bis es sich wieder über MOVE_THRESH_MM hinaus bewegt.
DisplayTarget prevRaw[MAX_TARGETS];       // Ground-Truth letzte Rohposition
uint32_t      stillSinceMs[MAX_TARGETS];  // Zeitpunkt der letzten echten Bewegung
const uint32_t STILL_TIMEOUT_MS = 2000;

uint32_t frameCount = 0;
uint32_t lastPacketMs = 0;
bool     txConnected = false;

// Buzzer-Status
uint32_t lastBeepMs   = 0;
bool     beepActive   = false;
uint8_t  chirpStage      = 0;   // 0=idle, 1/2/3=Sweep-Stufen (tief->mittel->Ziel)
uint32_t chirpStageStart = 0;
uint16_t chirpMainFreq   = 0;

// Hintergrund-Puls: läuft konstant, solange das Gerät an ist — unabhängig
// davon, ob ein Ziel erkannt wird. Signalisiert "Radar läuft/scannt".
const uint16_t PULSE_FREQ        = 300;   // Hz, Original-Wert
const uint16_t PULSE_DUR_MS      = 40;    // kurz, damit es nicht aufdringlich wird
const uint32_t PULSE_INTERVAL_MS = 1800;  // Pause zwischen zwei Pulsen
uint32_t lastPulseMs  = 0;
bool     pulseActive  = false;
uint32_t pulseStartMs = 0;

// ── UDP empfangen ──
// Wartende Datagramme abholen und das letzte gültige Paket anzeigen.
void receiveUdp() {
  static uint32_t lastDebug = 0;
  static uint32_t rxCount   = 0;
  UdpPacket pkt = {};
  bool gotPacket = false;
  int sz;
  while ((sz = udp.parsePacket()) > 0) {
    if (sz < (int)sizeof(UdpPacket)) continue;
    UdpPacket tmp = {};
    if (udp.read((uint8_t*)&tmp, sizeof(tmp)) != (int)sizeof(tmp)) continue;
    if (tmp.magic != 0xD03DA7A) continue;
    pkt = tmp;
    gotPacket = true;
    rxCount++;
  }
  if (millis() - lastDebug > 2000) {
    lastDebug = millis();
    Serial.print("UDP Pakete gesamt="); Serial.println(rxCount);
  }
  if (!gotPacket) return;

  frameCount = pkt.frameCount;
  lastPacketMs = millis();
  txConnected = true;

  for (int i = 0; i < MAX_TARGETS; i++) {
    if (pkt.targets[i].valid) {
      targets[i].x     = (float)pkt.targets[i].x;
      targets[i].y     = (float)pkt.targets[i].y;
      targets[i].spd   = (float)abs(pkt.targets[i].spd);
      targets[i].valid = true;
    } else {
      targets[i].valid = false;
    }
  }
}

// ── Maßstab ──
float distToR(float d) {
  if (d <= 0)       return 0;
  if (d <= 2000.0f) return (d/2000.0f)                          * 0.50f * RADAR_R;
  if (d <= 4000.0f) return (0.50f+(d-2000.0f)/2000.0f*0.25f)   * RADAR_R;
  if (d <= 6000.0f) return (0.75f+(d-4000.0f)/2000.0f*0.15f)   * RADAR_R;
  return              (0.90f+(d-6000.0f)/2000.0f*0.10f)         * RADAR_R;
}

void targetToPixel(float x, float y, int16_t &px, int16_t &py) {
  float dist  = sqrtf(x*x + y*y);
  float angle = atan2f(x, y) * 180.0f / PI;
  float r     = distToR(dist);
  float rad   = (angle - 90.0f) * PI / 180.0f;
  px = RADAR_CX + (int16_t)(r * cosf(rad));
  py = RADAR_CY + (int16_t)(r * sinf(rad));
}

// ── Hintergrund-Region neu zeichnen ──
void redrawBg(int16_t rx1, int16_t ry1, int16_t rw, int16_t rh) {
  int16_t rx2 = rx1+rw-1, ry2 = ry1+rh-1;
  if (rx1<0) rx1=0; if (ry1<0) ry1=0;
  if (rx2>=SCREEN_W) rx2=SCREEN_W-1;
  if (ry2>=SCREEN_H) ry2=SCREEN_H-1;
  if (rx1>rx2||ry1>ry2) return;
  display.fillRect(rx1,ry1,rx2-rx1+1,ry2-ry1+1,C_BG);
  for (int s=0; s<NUM_SECTORS; s++) {
    float c = SECTOR_CENTERS[s];
    float rd[]={1000,2000,3000,4000,5000,6000,7000,8000};
    uint16_t rc[]={C_GREEN,0x00C0,0x00C0,C_GDIM,0x00C0,0x00C0,0x00C0,C_GREEN};
    for (int ri=0; ri<8; ri++) {
      float r=distToR(rd[ri]);
      for (float a=c-SECTOR_HALF; a<=c+SECTOR_HALF; a+=0.5f) {
        float rad=(a-90.0f)*PI/180.0f;
        int16_t px=RADAR_CX+(int16_t)(r*cosf(rad)), py=RADAR_CY+(int16_t)(r*sinf(rad));
        if (px>=rx1&&px<=rx2&&py>=ry1&&py<=ry2) display.drawPixel(px,py,rc[ri]);
      }
    }
    int degs[]={-60,-30,0,30,60};
    for (int i=0; i<5; i++) {
      float rad=(c+degs[i]-90.0f)*PI/180.0f;
      for (float r=0; r<=RADAR_R; r+=1.5f) {
        int16_t px=RADAR_CX+(int16_t)(r*cosf(rad)), py=RADAR_CY+(int16_t)(r*sinf(rad));
        if (px>=rx1&&px<=rx2&&py>=ry1&&py<=ry2) display.drawPixel(px,py,degs[i]==0?C_GDIM:0x0200);
      }
    }
  }
  if (RADAR_CX>=rx1&&RADAR_CX<=rx2&&RADAR_CY>=ry1&&RADAR_CY<=ry2) {
    display.fillCircle(RADAR_CX,RADAR_CY,5,C_GREEN);
    display.drawCircle(RADAR_CX,RADAR_CY,9,C_GDIM);
  }
}

// ── Aktive Dots neu zeichnen, die von einer Region betroffen sein könnten ──
// (z.B. nachdem redrawBg() über sie drübergemalt hat)
void redrawDotsInRegion(int16_t rx1, int16_t ry1, int16_t rw, int16_t rh) {
  int16_t rx2 = rx1 + rw - 1, ry2 = ry1 + rh - 1;
  for (int i = 0; i < MAX_TARGETS; i++) {
    if (!dots[i].active) continue;
    if (dots[i].bx <= rx2 && dots[i].bx + dots[i].bw - 1 >= rx1 &&
        dots[i].by <= ry2 && dots[i].by + dots[i].bh - 1 >= ry1) {
      drawDot(i);
    }
  }
}

// ── Sichtbarer Sonar-Ping: ein Ring, der vom Ursprung nach außen läuft ──
void drawPingRing(float r, uint16_t color) {
  for (int s = 0; s < NUM_SECTORS; s++) {
    float c = SECTOR_CENTERS[s];
    for (float a = c - SECTOR_HALF; a <= c + SECTOR_HALF; a += 0.5f) {
      float rad = (a - 90.0f) * PI / 180.0f;
      int16_t px = RADAR_CX + (int16_t)(r * cosf(rad));
      int16_t py = RADAR_CY + (int16_t)(r * sinf(rad));
      if (px < 0 || px >= SCREEN_W || py < 0 || py >= SCREEN_H) continue;
      // Range-HUD-Bar an der Basis aussparen, sonst überschreibt der
      // durchlaufende Ping kurzzeitig die Zahl
      if (px >= RANGE_HUD_X && px <= RANGE_HUD_X + RANGE_HUD_W &&
          py >= RANGE_HUD_Y && py <= RANGE_HUD_Y + RANGE_HUD_H) continue;
      display.drawPixel(px, py, color);
    }
  }
}

// Hintergrundfarbe, die an Radius r "eigentlich" stehen würde (feste
// Range-Ring-Farbe falls Treffer, sonst normale BG-Farbe) — für das
// günstige Zurückschreiben beim Löschen des Ping-Rings.
uint16_t bgColorAtRadius(float r) {
  float rangeMm[]  = {1000,2000,3000,4000,5000,6000,7000,8000};
  uint16_t rangeCol[] = {C_GREEN,0x00C0,0x00C0,C_GDIM,0x00C0,0x00C0,0x00C0,C_GREEN};
  for (int k = 0; k < 8; k++) {
    if (fabsf(distToR(rangeMm[k]) - r) < 1.0f) return rangeCol[k];
  }
  return C_BG;
}

// Bounding-Box eines Rings bei Radius r über alle Sektoren hinweg — NUR
// zur groben Prüfung, ob ein Dot vom Ring gekreuzt wird, NICHT für einen
// vollflächigen Redraw (der wäre bei einem 120°-Bogen riesig und würde
// weit entfernte UI-Elemente wie Info-Box/Button mit überschreiben).
void ringBoundingBox(float r, int16_t &bx1, int16_t &by1, int16_t &bx2, int16_t &by2) {
  float minA = SECTOR_CENTERS[0] - SECTOR_HALF;
  float maxA = SECTOR_CENTERS[NUM_SECTORS-1] + SECTOR_HALF;
  bx1 = 32000; by1 = 32000; bx2 = -32000; by2 = -32000;
  for (float a = minA; a <= maxA; a += 2.0f) {
    float rad = (a - 90.0f) * PI / 180.0f;
    int16_t px = RADAR_CX + (int16_t)(r * cosf(rad));
    int16_t py = RADAR_CY + (int16_t)(r * sinf(rad));
    if (px < bx1) bx1 = px; if (px > bx2) bx2 = px;
    if (py < by1) by1 = py; if (py > by2) by2 = py;
  }
  bx1 -= 2; by1 -= 2; bx2 += 2; by2 += 2;
}

// Sweep-Dauer bewusst etwas kürzer als PULSE_INTERVAL_MS (Puls löst den
// Ring aus, siehe triggerPing() in updateBackgroundPulse) — Ring läuft
// exakt im Takt des Sounds, kein eigener Pause-Timer mehr nötig.
const float    PING_SPEED_PX_MS = 440.0f / (PULSE_INTERVAL_MS - 200.0f);
const uint32_t PING_FRAME_MS    = 40;                // ~25 FPS für die Animation

float    pingRadius        = 0;
float    pingPrevRadius    = -1;
bool     pingRunning        = false;
uint32_t lastPingFrameMs   = 0;

// Wird vom Sound-Puls aufgerufen — startet den Ring exakt im gleichen Moment
void triggerPing() {
  pingRadius   = 0;
  pingRunning  = true;
}

void updatePing() {
  uint32_t now = millis();
  if (now - lastPingFrameMs < PING_FRAME_MS) return;
  float dt = (float)(now - lastPingFrameMs);
  lastPingFrameMs = now;

  // Alten Ring löschen: NUR die exakt gleichen Pixel zurückschreiben, die
  // gezeichnet wurden (billig, ~240 Punkte) statt eine teure
  // Bounding-Box-Fläche über redrawBg() neu zu zeichnen (das kostet pro
  // Aufruf zehntausende Iterationen und malt dabei über Info-Box/Button).
  if (pingPrevRadius >= 0) {
    drawPingRing(pingPrevRadius, bgColorAtRadius(pingPrevRadius));
    int16_t bx1, by1, bx2, by2;
    ringBoundingBox(pingPrevRadius, bx1, by1, bx2, by2);
    redrawDotsInRegion(bx1, by1, bx2 - bx1 + 1, by2 - by1 + 1);
    pingPrevRadius = -1;
  }

  if (!pingRunning) return;

  drawPingRing(pingRadius, C_GREEN);
  pingPrevRadius = pingRadius;
  pingRadius += PING_SPEED_PX_MS * dt;

  if (pingRadius > RADAR_R) {
    pingRunning = false;
  }
}

// ── Hintergrund initial ──
void drawBackground() {
  display.fillScreen(C_BG);
  for (int s=0; s<NUM_SECTORS; s++) {
    float c = SECTOR_CENTERS[s];

    float rd[]={1000,2000,3000,4000,5000,6000,7000,8000};
    uint16_t rc[]={C_GREEN,0x00C0,0x00C0,C_GDIM,0x00C0,0x00C0,0x00C0,C_GREEN};
    for (int ri=0; ri<8; ri++) {
      float r=distToR(rd[ri]);
      for (float a=c-SECTOR_HALF; a<=c+SECTOR_HALF; a+=0.5f) {
        float rad=(a-90.0f)*PI/180.0f;
        int16_t px=RADAR_CX+(int16_t)(r*cosf(rad)), py=RADAR_CY+(int16_t)(r*sinf(rad));
        if (px>=0&&px<SCREEN_W&&py>=0&&py<SCREEN_H) display.drawPixel(px,py,rc[ri]);
      }
      // Distanz-Label nur an der äußeren rechten Kante von Sektor 0 setzen,
      // sonst würden sich die Labels beider Sektoren an der gemeinsamen
      // Nahtstelle (60°) überlappen.
      if (s==0) {
        display.setTextColor(ri==0||ri==7?C_GREEN:0x0380); display.setTextSize(1);
        char buf[8]; sprintf(buf,"%.0fm",rd[ri]/1000.0f);
        float rR=(c+SECTOR_HALF+6.0f-90.0f)*PI/180.0f;  // etwas außerhalb der Randlinie, nicht mehr drauf
        int16_t lx=RADAR_CX+(int16_t)((r+4)*cosf(rR))+4, ly=RADAR_CY+(int16_t)((r+4)*sinf(rR))-4;
        if (lx>=0&&lx<SCREEN_W&&ly>=0&&ly<SCREEN_H) { display.setCursor(lx,ly); display.print(buf); }
      }
    }

    float radL=(c-SECTOR_HALF-90.0f)*PI/180.0f, radR=(c+SECTOR_HALF-90.0f)*PI/180.0f;
    for (int off=-1; off<=1; off++) {
      display.drawLine(RADAR_CX+off,RADAR_CY,RADAR_CX+off+(int16_t)(RADAR_R*cosf(radL)),RADAR_CY+(int16_t)(RADAR_R*sinf(radL)),C_GREEN);
      display.drawLine(RADAR_CX+off,RADAR_CY,RADAR_CX+off+(int16_t)(RADAR_R*cosf(radR)),RADAR_CY+(int16_t)(RADAR_R*sinf(radR)),C_GREEN);
    }

    int degs[]={-60,-30,0,30,60};
    for (int i=0; i<5; i++) {
      float rad=(c+degs[i]-90.0f)*PI/180.0f;
      display.drawLine(RADAR_CX,RADAR_CY,RADAR_CX+(int16_t)(RADAR_R*cosf(rad)),RADAR_CY+(int16_t)(RADAR_R*sinf(rad)),degs[i]==0?C_GDIM:0x0260);
      char buf[5]; sprintf(buf,"%d",(int)(c+degs[i]));
      float lr=RADAR_R+14.0f;
      int16_t lx=RADAR_CX+(int16_t)(lr*cosf(rad))-6, ly=RADAR_CY+(int16_t)(lr*sinf(rad))-4;
      if (lx>=0&&lx<SCREEN_W&&ly>=0) { display.setTextColor(degs[i]==0?C_GREEN:0x0380); display.setTextSize(1); display.setCursor(lx,ly); display.print(buf); }
    }
  }
  display.fillCircle(RADAR_CX,RADAR_CY,5,C_GREEN);
  display.drawCircle(RADAR_CX,RADAR_CY,9,C_GDIM);
  // Info-Box
  display.fillRect(670,0,130,70,0x0820);
  display.setTextColor(C_GDIM); display.setTextSize(1);
  display.setCursor(675, 4); display.print("RD-03D 24GHz");
  display.setCursor(675,14); display.print("3T 8m 120deg");
  display.setCursor(675,24); display.print("AP: RadarNet");
}

// 3 Targets vom einzigen Sensor
static const uint16_t DOT_COLS[MAX_TARGETS] = {C_RED, C_AMBER, C_CYAN};

void eraseDot(int i) {
  if (!dots[i].active) return;
  redrawBg(dots[i].bx, dots[i].by, dots[i].bw, dots[i].bh);
  dots[i].active = false;
}

void drawDot(int i) {
  int16_t tx, ty;
  targetToPixel(targets[i].x, targets[i].y, tx, ty);
  uint16_t col = DOT_COLS[i];
  int16_t bx=tx-22, by=ty-22, bw=44, bh=44;
  display.drawCircle(tx,ty,18,col);
  display.drawCircle(tx,ty,11,col);
  display.fillCircle(tx,ty, 5,col);
  dots[i]      = {tx,ty,bx,by,bw,bh,true};
  lastDrawn[i] = targets[i];
}

bool staleNow[MAX_TARGETS];

// ── Distanz-Labels fest am Ursprung statt am beweglichen Punkt ──
// Fester, umrandeter Kasten unter dem Mute-Button — nicht mehr am
// beweglichen Ursprung, sondern in der gleichen UI-Spalte wie Info-Box
// und Button. Malt sich komplett selbst neu (eigener Hintergrund-Fill),
// braucht kein redrawBg() und kann daher auch nichts anderes überschreiben.
#define TGT_BOX_X   10
#define TGT_BOX_Y   400
#define TGT_BOX_W   130
#define TGT_BOX_LINE_H 14
#define TGT_BOX_H   (MAX_TARGETS * TGT_BOX_LINE_H + 16)
const uint32_t TGT_BOX_INTERVAL_MS = 150;
uint32_t lastTgtBoxMs = 0;

void drawTargetBox() {
  display.fillRect(TGT_BOX_X, TGT_BOX_Y, TGT_BOX_W, TGT_BOX_H, 0x0820);
  display.drawRect(TGT_BOX_X, TGT_BOX_Y, TGT_BOX_W, TGT_BOX_H, C_GDIM);
  display.setTextColor(C_GDIM); display.setTextSize(1);
  display.setCursor(TGT_BOX_X + 6, TGT_BOX_Y + 4);
  display.print("TARGETS");

  display.setTextSize(1);
  int line = 0;
  for (int i = 0; i < MAX_TARGETS; i++) {
    if (!targets[i].valid || staleNow[i]) continue;
    float dist = sqrtf(targets[i].x*targets[i].x + targets[i].y*targets[i].y);
    char buf[20];
    if (targets[i].spd > 2.0f) sprintf(buf, "T%d %.2fm %dcm/s", i+1, dist/1000.0f, (int)targets[i].spd);
    else                       sprintf(buf, "T%d %.2fm", i+1, dist/1000.0f);
    display.setTextColor(DOT_COLS[i]);
    display.setCursor(TGT_BOX_X + 6, TGT_BOX_Y + 16 + line * TGT_BOX_LINE_H);
    display.print(buf);
    line++;
  }
}

void updateTargetBox() {
  if (millis() - lastTgtBoxMs < TGT_BOX_INTERVAL_MS) return;
  lastTgtBoxMs = millis();
  drawTargetBox();
}

// ── Großer Range-Readout an der Basis der Radar-Kuppel (Ursprungspunkt) ──
// Referenz: Tracker-UI mit großer Zahl direkt unter der Scope-Grafik.
// Bei unserem Layout sitzt der Ursprung am unteren Bildschirmrand, daher
// wird die Bar dort platziert statt "unter" dem Bogen — überdeckt den
// Ursprungsmarker bewusst, genau wie im Referenzbild der Fokuspunkt der
// Kuppel durch die Zahl ersetzt wird.
const uint32_t RANGE_HUD_INTERVAL_MS = 150;
uint32_t lastRangeHudMs = 0;

void drawRangeHud() {
  display.fillRect(RANGE_HUD_X, RANGE_HUD_Y, RANGE_HUD_W, RANGE_HUD_H, 0x0000);
  display.drawRect(RANGE_HUD_X, RANGE_HUD_Y, RANGE_HUD_W, RANGE_HUD_H, C_GDIM);

  float dist = closestTargetDistMm();
  display.setTextSize(3);
  char buf[10];
  if (dist >= 0) {
    display.setTextColor(C_RED);
    sprintf(buf, "%.2fm", dist/1000.0f);
  } else {
    display.setTextColor(C_GDIM);
    sprintf(buf, "---");
  }
  int16_t textW = strlen(buf) * 18;  // grobe Breitenschätzung bei textSize(3)
  display.setCursor(RADAR_CX - textW/2, RANGE_HUD_Y + (RANGE_HUD_H - 24) / 2);
  display.print(buf);

  // Ziel-Dots, die von der Bar überdeckt wurden, wiederherstellen
  redrawDotsInRegion(RANGE_HUD_X, RANGE_HUD_Y, RANGE_HUD_W, RANGE_HUD_H);
}

void updateRangeHud() {
  if (millis() - lastRangeHudMs < RANGE_HUD_INTERVAL_MS) return;
  lastRangeHudMs = millis();
  drawRangeHud();
}

void updateDots() {
  uint32_t now = millis();
  for (int i = 0; i < MAX_TARGETS; i++) {
    staleNow[i] = false;
    if (!targets[i].valid) {
      stillSinceMs[i] = 0;
      prevRaw[i].valid = false;
      if (dots[i].active) eraseDot(i);
      continue;
    }

    // Echte Bewegung seit dem letzten Frame? (Ground-Truth, unabhängig vom
    // Rendering — läuft auch weiter, wenn der Punkt gerade ausgeblendet ist)
    bool movedRaw = !prevRaw[i].valid ||
                    fabsf(targets[i].x - prevRaw[i].x) > MOVE_THRESH_MM ||
                    fabsf(targets[i].y - prevRaw[i].y) > MOVE_THRESH_MM;
    if (movedRaw) stillSinceMs[i] = now;
    prevRaw[i] = targets[i];

    bool stale = (now - stillSinceMs[i]) > STILL_TIMEOUT_MS;
    staleNow[i] = stale;
    if (stale) {
      if (dots[i].active) eraseDot(i);
      continue;  // ausgeblendet, Tracking läuft im Hintergrund weiter
    }

    bool moved = fabsf(targets[i].x - lastDrawn[i].x) > MOVE_THRESH_MM ||
                 fabsf(targets[i].y - lastDrawn[i].y) > MOVE_THRESH_MM;
    if (dots[i].active && !moved) continue;
    if (dots[i].active) eraseDot(i);
    drawDot(i);
  }

  // Info-Box aktualisieren (nur noch Verbindungsstatus — Zielanzahl/Distanz
  // stehen jetzt in der TARGETS-Box und im Range-HUD, keine Duplikate mehr)
  display.fillRect(671,34,128,36,0x0820);

  // Verbindungsstatus zum XIAO (Transmitter)
  bool alive = (millis() - lastPacketMs) < 3000;
  display.setTextColor(alive ? C_GREEN : C_RED); display.setTextSize(1);
  display.setCursor(675,36);
  display.print(alive ? "TX: OK  " : "TX: ---  ");
  char fb[16]; snprintf(fb, sizeof(fb), "fr:%lu", (unsigned long)frameCount);
  display.print(fb);
}

uint32_t lastUptimeMs = 0;
void updateUptime() {
  if (millis()-lastUptimeMs < 1000) return;
  lastUptimeMs = millis();
  // Verbindungsverlust: alle Dots löschen
  if ((millis() - lastPacketMs) > 3000 && txConnected) {
    for (int i=0; i<MAX_TARGETS; i++) {
      targets[i].valid = false;
      if (dots[i].active) eraseDot(i);
    }
  }
}

// ── Periodischer Voll-Redraw gegen "Schatten-Streifen" ──
// Die regionalen Teil-Redraws (redrawBg beim Dot-Löschen) summieren über
// Zeit kleine Rundungsdifferenzen zu sichtbaren Artefakten. Ein kompletter
// Neuzeichnen-Durchlauf alle 10s beseitigt das zuverlässig.
uint32_t lastBgRefreshMs = 0;
const uint32_t BG_REFRESH_INTERVAL_MS = 10000;

void refreshBackground() {
  drawBackground();
  drawMuteButton();
  for (int i = 0; i < MAX_TARGETS; i++) {
    dots[i].active = false;
    if (targets[i].valid) drawDot(i);
  }
  drawTargetBox();
  drawRangeHud();
  pingPrevRadius = -1;  // Ping-Ring-Status zurücksetzen, Bildschirm ist frisch
}

// ── Tracker-Sound ──

// Entfernung des nächstgelegenen validen Targets in mm, -1 wenn keins
float closestTargetDistMm() {
  float best = -1.0f;
  for (int i = 0; i < MAX_TARGETS; i++) {
    if (!targets[i].valid || staleNow[i]) continue;
    float d = sqrtf(targets[i].x * targets[i].x + targets[i].y * targets[i].y);
    if (best < 0 || d < best) best = d;
  }
  return best;
}
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
void loop() {
  receiveUdp();
  updateDots();
  updateTargetBox();
  updateRangeHud();
  updatePing();
  updateUptime();
  updateTrackerSound();
  updateBackgroundPulse();
  checkTouch();

  if (millis() - lastBgRefreshMs >= BG_REFRESH_INTERVAL_MS) {
    lastBgRefreshMs = millis();
    refreshBackground();
  }
}

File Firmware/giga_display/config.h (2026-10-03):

/*
 * config.h — build-time settings for the GIGA R1 display node
 *
 * Edit this file, not the sketch.
 */
#ifndef GIGA_DISPLAY_CONFIG_H
#define GIGA_DISPLAY_CONFIG_H

/* ------------------------------------------------------------------- Wi-Fi */
/* Must match Firmware/sensor_node_esp32s3/config.h. The sensor node hosts
 * the network; this display joins it as a client.                            */
#define WIFI_SSID                        "RadarSystem"
#define WIFI_PASS                        "change-me-before-use"
#define WIFI_CONNECT_TIMEOUT_MS          8000   /* one blocking connect attempt     */
#define WIFI_RETRY_MS                    3000   /* pause between attempts           */
#define WIFI_RECONNECT_AFTER_SILENCE_MS  15000  /* no packets at all -> reconnect   */

/* What this display asks the sensor node to send (RL_WANT_* bits). Clear the
 * LIDAR bit for a radar-only display.                                         */
#define RECEIVER_WANTS   (RL_WANT_RADAR | RL_WANT_LIDAR | RL_WANT_STATUS)

/* ------------------------------------------------------------------- LIDAR */
/* Rotate the point cloud so the sensor node's "forward" is at the top of the
 * screen. The LD19's zero angle is wherever its connector points; measure it
 * once (docs/TESTING.md, "Calibration") and put the result here.              */
#define LIDAR_ANGLE_OFFSET_DEG   0.0f
#define LIDAR_CLOCKWISE          1      /* LD19 angles increase clockwise from above */
#define LIDAR_POINT_TTL_MS       500    /* a bucket not refreshed for this long fades */
#define LIDAR_SHOWN_AT_BOOT      1

/* ------------------------------------------------------------------- radar */
#define RADAR_MIRROR_X           0      /* 1 if "walk left" moves the dot right  */
#define RADAR_HOLD_MS            400    /* keep showing the last targets this long */
#define RADAR_STILL_TIMEOUT_MS   2000   /* hide a target that stopped moving; 0 = off */
#define RADAR_MOVE_THRESH_MM     15
#define RADAR_FOV_HALF_DEG       60.0f  /* RD-03D field of view is +/-60 degrees */
#define RADAR_MAX_RANGE_M        8.0f

/* --------------------------------------------------------------------- view */
#define ZOOM_LEVELS_M            {4.0f, 8.0f, 12.0f}   /* tap ZOOM to cycle     */
#define ZOOM_DEFAULT_INDEX       1
#define FRAME_INTERVAL_MS        66     /* ~15 fps full redraw                   */

/* ------------------------------------------------------------------ buzzer */
/* Passive piezo on D9. Power it from 3V3: GIGA pins are not 5 V tolerant.      */
#define BUZZER_PIN               9
#define BUZZER_MUTED_AT_BOOT     0
#define BEEP_DUR_MS              70
#define BEEP_DIST_MIN_MM         300.0f /* fastest, highest ping                 */
#define BEEP_DIST_MAX_MM         8000.0f
#define BEEP_INTERVAL_MIN_MS     120
#define BEEP_INTERVAL_MAX_MS     900
#define BEEP_FREQ_MIN_HZ         700
#define BEEP_FREQ_MAX_HZ         1800

/* -------------------------------------------------------------- diagnostics */
#define DEBUG_INTERVAL_MS        2000

#endif /* GIGA_DISPLAY_CONFIG_H */

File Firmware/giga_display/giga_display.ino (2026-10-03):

/*
 * giga_display.ino — RadarLink display node (Arduino GIGA R1 WiFi + GIGA Display Shield)
 *
 * Joins the sensor node's Wi-Fi network as a client, announces itself with a
 * HELLO packet once a second and draws what the sensor node sends: a 360-degree
 * LIDAR outline of the room (LD19, 720 angle buckets) with the radar's moving
 * targets overlaid in the +/-60-degree sector in front of the sensor. Passive
 * buzzer pings speed up and rise in pitch as the closest target approaches.
 * Touch buttons: MUTE, ZOOM (4 / 8 / 12 m), LIDAR on/off.
 *
 * Changes versus the v1 receiver, all from the audit of that code:
 *   - client (STA) mode: the sensor node is the access point, so a second
 *     display (uConsole) can receive the same stream; boot order no longer matters
 *   - every pending UDP datagram is drained each loop (v1 read one per loop
 *     while each dot erase cost ~125k trig calls, so it fell behind and stayed behind)
 *   - whole frame redrawn with cheap primitives into the GFX canvas at ~15 fps,
 *     no per-pixel trig loops, no 10-second full-screen flicker
 *   - packets accepted only from the sensor node's address, sequence numbers checked
 *   - #include <WiFiUdp.h> with the case the core actually ships (v1 only
 *     compiled on case-insensitive file systems)
 *   - a failed Wi-Fi connection is shown on screen and retried, never silent
 *
 * Board: "Arduino GIGA R1 WiFi" from the Arduino Mbed OS GIGA Boards core 4.x.
 * Libraries: Arduino_GigaDisplay_GFX (+ Adafruit GFX Library), Arduino_GigaDisplayTouch.
 * Credits: v1 display, buzzer and touch handling by Sudo_solder (MIT).
 *
 * SPDX-License-Identifier: MIT
 */
#include <WiFi.h>
#include <WiFiUdp.h>
#include "Arduino_GigaDisplay_GFX.h"
#include "Arduino_GigaDisplayTouch.h"
#include "pinDefinitions.h"
#include "mbed.h"

#include "config.h"
#include "radar_protocol.h"

/* ------------------------------------------------------------- constants */
#define SCREEN_W   800
#define SCREEN_H   480
static const int16_t PLOT_CX = 400;
static const int16_t PLOT_CY = 240;
static const int16_t PLOT_R  = 222;
static const int16_t HUD_LEFT_X  = 6;
static const int16_t HUD_RIGHT_X = 636;
static const int16_t HUD_RIGHT_W = 158;

/* RGB565 */
#define C_BG       0x0000
#define C_GRID     0x01E0
#define C_GRID_DIM 0x00C0
#define C_SECTOR   0x0320
#define C_GREEN    0x07E0
#define C_GDIM     0x02E0
#define C_RED      0xF800
#define C_AMBER    0xFD20
#define C_CYAN     0x07FF
#define C_WHITE    0xFFFF
#define C_GREY     0x8410
#define C_LIDAR0   0xAFE5   /* fresh point */
#define C_LIDAR1   0x5E04
#define C_LIDAR2   0x2C83   /* oldest */
#define C_BTN_ON   0x0320
#define C_BTN_OFF  0x4000

static const uint16_t SLOT_COLOUR[RL_RADAR_SLOTS] = {C_RED, C_AMBER, C_CYAN};
static const float    ZOOM_RANGES_M[] = ZOOM_LEVELS_M;
static const uint8_t  ZOOM_COUNT = sizeof(ZOOM_RANGES_M) / sizeof(ZOOM_RANGES_M[0]);
#define LIDAR_BUCKETS 720                     /* 0.5 degree each */

/* --------------------------------------------------------------- objects */
GigaDisplay_GFX          display;
Arduino_GigaDisplayTouch touch;
WiFiUDP                  udp;

/* -------------------------------------------------------------- link state */
static bool      linkUp = false;
static IPAddress senderIP;
static uint32_t  lastConnectAttemptMs = 0, lastHelloMs = 0, lastPacketMs = 0;
static uint16_t  helloSeq = 0;
static uint16_t  lastSeq[4];          /* indexed by packet type 1..3 */
static bool      haveSeq[4];
static uint8_t   oldStreak[4];
static uint32_t  rxPackets = 0, rxDropped = 0, rxForeign = 0, rxThisSec = 0, rxPerSec = 0;
static uint8_t   rxBuf[RL_MAX_PACKET];
static int       lastWifiResult = -1;

/* ----------------------------------------------------------------- lidar */
struct LidarBucket { uint16_t dist_mm; uint8_t intensity; uint32_t ts; };
static LidarBucket buckets[LIDAR_BUCKETS];
static float       bucketSin[LIDAR_BUCKETS], bucketCos[LIDAR_BUCKETS];
static bool        lidarVisible = LIDAR_SHOWN_AT_BOOT != 0;
static uint32_t    lastLidarMs = 0;

/* ----------------------------------------------------------------- radar */
static RlRadarPacket radar;
static uint32_t      lastRadarMs = 0;
struct Track { int16_t x, y; uint32_t stillSinceMs; bool have; };
static Track track[RL_RADAR_SLOTS];
static bool  targetShown[RL_RADAR_SLOTS];

/* ---------------------------------------------------------------- status */
static RlStatusPacket nodeStatus;
static bool           haveStatus = false;

/* -------------------------------------------------------------------- UI */
struct Button { int16_t x, y, w, h; };
static const Button BTN_LIDAR = {HUD_RIGHT_X, 324, HUD_RIGHT_W, 42};
static const Button BTN_MUTE  = {HUD_RIGHT_X, 376, HUD_RIGHT_W, 42};
static const Button BTN_ZOOM  = {HUD_RIGHT_X, 428, HUD_RIGHT_W, 42};
static uint8_t  zoomIdx = ZOOM_DEFAULT_INDEX;
static bool     buzzerMuted = BUZZER_MUTED_AT_BOOT != 0;
static bool     touchDownLast = false;
static uint32_t lastTouchToggleMs = 0;

/* ---------------------------------------------------------------- buzzer */
/* The Mbed core's tone() allocates a DigitalOut on every call and never frees
 * it (Tone::stop() nulls the pointer before the destructor deletes it), so a
 * sketch that pings several times a second exhausts the heap after an hour or
 * two. Drive the piezo with one Ticker + DigitalOut owned by the sketch instead. */
static mbed::DigitalOut *buzzerOut = nullptr;
static mbed::Ticker      buzzerTicker;
static uint32_t lastBeepMs = 0, beepStartMs = 0;
static bool     beepActive = false;
static int32_t  cachedRssi = 0;
static uint32_t lastTouchPollMs = 0;

static void buzzerToggle() { if (buzzerOut) *buzzerOut = !*buzzerOut; }
static void buzzerStart(uint16_t freqHz) {
    if (!buzzerOut || freqHz == 0) return;
    buzzerTicker.detach();
    buzzerTicker.attach(mbed::callback(buzzerToggle), std::chrono::microseconds(500000UL / freqHz));
}
static void buzzerStop() {
    buzzerTicker.detach();
    if (buzzerOut) *buzzerOut = 0;
}

/* ---------------------------------------------------------------- timing */
static uint32_t lastFrameMs = 0, lastSecondMs = 0, lastDebugMs = 0, framesThisSec = 0, fps = 0;

/* ================================================================ helpers */
static inline bool alive(uint32_t now) { return linkUp && lastPacketMs && (now - lastPacketMs) < RL_LINK_TIMEOUT_MS; }
static inline float rangeM() { return ZOOM_RANGES_M[zoomIdx]; }
static inline float pxPerMm() { return (float)PLOT_R / (rangeM() * 1000.0f); }
static inline bool inButton(const Button &b, int16_t x, int16_t y) { return x >= b.x && x < b.x + b.w && y >= b.y && y < b.y + b.h; }

static void resetSeqTracking() {
    for (int i = 0; i < 4; i++) { haveSeq[i] = false; oldStreak[i] = 0; lastSeq[i] = 0; }
}
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

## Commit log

2026-10-03 Merge radar + LIDAR into one sensor node with GIGA and uConsole receivers
    Rework the v1 single-radar/single-display project into a three-node system:
    * Firmware/sensor_node_esp32s3: XIAO ESP32-S3 hosts the Wi-Fi AP, reads the
    RD-03D radar (UART1) and optionally an LDROBOT LD19 2D LIDAR (UART2), and
    unicasts RADAR/LIDAR/STATUS packets to every receiver that sends HELLO.
    Non-blocking radar configuration, sentinel-speed filter, 1 m clustering,
    LD19 CRC-8 parsing, lidar batches capped at 492 bytes for the GIGA's
    508-byte UDP buffer. Parsers are Arduino-free and unit tested on the host.
    * Firmware/giga_display: GIGA R1 joins the node as a client, drains all UDP
    each loop, redraws a 3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
    [config.h, giga_display.ino, ld19_parser.h]
2026-10-03 Fix review findings: UDP buffer jam, tone() leak, viewer default node
    Independent review of the new code against the library sources found:
    * Sensor node: pollHello() read at most 64 bytes of each datagram and never
    flushed the rest. In arduino-esp32 (2.x and 3.x) parsePacket() returns 0
    while a partially read datagram remains buffered, so a single oversized
    stray packet would have silenced HELLO reception until power-cycle. The
    buffer is now flushed after every read. Also: wrap-safe oldest-subscriber
    comparison, and Serial.setTxTimeoutMs(0) under USB CDC so a host that
    stopped reading the port cannot stall the loop for 2 s per print.
    * GIGA display: the Mbed core's tone() leaks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
    [giga_display.ino, sensor_node_esp32s3.ino]
2026-10-03 Sensor node: use clear() on esp32 3.x, verified against core 3.3.12
    The esp32 3.3.12 core now installs here (its dfu-util tool dependency, which
    compiling does not need, came from the blocked Arduino index). Both sensor
    node build levels and the upstream transmitter fix branch compile against it
    with no warnings; flush() is deprecated in 3.x in favour of clear(), so the
    call is now selected by ESP_ARDUINO_VERSION_MAJOR.
    Claude-Session: https://claude.ai/code/session_01TGbEMWcJoFY7rARJoCEYFt
    [sensor_node_esp32s3.ino]
2026-10-03 uConsole: intrusion detection with baseline learning and radar fusion
    New uconsole/radar_intrusion.py (pure Python, 30 tests in total now pass):
    * ReferenceScan learns the empty room over a learning window: median LIDAR
    distance per 0.5-degree bucket, buckets classified reliable / open (no
    return, e.g. a corridor beyond range) / unreliable (flicker, excluded).
    Saved to and loaded from baseline.json.
    * IntrusionDetector flags buckets at least delta_mm (300) closer than the
    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
2026-10-03 Relay daemon with web view, detector zones/schedule/snapshots, CI
    * uconsole/radar_relay.py: headless hub. Subscribes to the sensor node like a
    receiver and re-serves the unchanged datagrams to remote viewers that HELLO
    it (radar_viewer.py --node <relay>), so a laptop on a Tailscale tailnet can
    watch through the uConsole's 4G link while the node stays on its own Wi-Fi.
    Runs the intrusion detector without a display and serves a phone-friendly
    web view: GET / (canvas plot, HUD), GET /state.json, POST /arm /disarm
    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
2026-10-03 Level 2 enclosure draft (OpenSCAD), CAD README, CI badge
    CAD files/level2_sensor_node.scad: parametric box for the radar + LIDAR node
    (XIAO, RD-03D behind a 1.2 mm front window, MT3608, TP4056, 103450 cell,
    switch, indicator) with the LD19 bolted on the lid for a clear 360-degree
    view; rendered base/lid STLs and an assembly preview. Designed from datasheet
    dimensions, never printed: the LD19 hole pattern is a guess and every module
    size is a parameter to be measured first, as CAD files/README.md spells out.
    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
    [level2_sensor_node.scad, level2_sensor_node_base.stl, level2_sensor_node_lid.stl]
2026-10-05 Firmware 1.1: sketch folders the IDE can open, README paths and radar power row
    * The Arduino IDE only opens a sketch whose folder carries the sketch's own
    name. "Firmware 1.1/rd03d_giga_receiver v1.1/rd03d_giga_receiver.ino" and
    "Firmware 1.1/rd03d_xiao_s3_sender v1.1/rd03d_xiao_s3_sender.ino" therefore
    trigger the "move the sketch into a folder" prompt. Renamed the two folders
    to rd03d_giga_receiver and rd03d_xiao_s3_sender (the "Firmware 1.1" parent
    is kept). Both sketches compile unchanged.
    * README "Firmware" section pointed at Firmware/rd03d_xiao_s3_transmitter/...
    and Firmware/rd03d_giga_receiver/..., which no longer exist; updated to the
    Firmware 1.1 paths.
    * The RD-03D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
    [rd03d_giga_receiver.ino, rd03d_xiao_s3_sender.ino]
2026-11-04 Add a serial console with self-diagnosis and raw UART capture to the sensor node
    Typing in the serial monitor now talks to the node. `diag` turns the counters
    the sketch already keeps into verdicts (no bytes = power or pin, bytes without
    frames = baud rate, bad tails or CRC errors = lost bytes or ripple, stations
    without subscribers = no HELLO), with the thresholds in node_diag.h so the host
    tests and tools/analyze_log.py share them. `raw radar [N]` / `raw lidar [N]`
    copy the next N UART bytes into RAM while the parsers keep running and print
    them as hex, a few lines per loop() pass, for tools/decode_capture.py. `subs`
    lists the receivers, `wifi` the joined stations with RSSI and IP
    (esp_wif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
2026-11-04 Add Python sensor parsers, a capture decoder, a serial probe and a log analyzer
    uconsole/radar_sensors.py mirrors rd03d_parser.h and ld19_parser.h (frame
    sync, sign-magnitude decoding, sentinel and range gating, clustering with C
    truncation, CRC-8/0x4D, angle interpolation) and analyses a byte stream into
    frames, configuration replies and hints. tests/test_sensors.py builds streams
    of good, corrupt and truncated frames and compares every decoded value with
    the C++ headers compiled on the host (sensor_vectors.cpp).
    tools/decode_capture.py decodes the hex the node prints for `raw radar` /
    `raw lidar` (or any hex dump, C array or binary file) and names the classic
    faults: wrong baud rate, idle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
2026-11-04 Add the uConsole installer and doctor
    uconsole/install.sh installs the Debian packages, creates the NetworkManager
    profile for the node's network (ipv4.never-default so another uplink stays the
    default route, Wi-Fi power save off, endless autoconnect retries, password
    masked in the output), writes the viewer's XDG autostart entry
    (--viewer-autostart) and/or the relay systemd unit with the real paths and
    user (--relay, --web-port, --web-token), opens ufw for UDP 4210 when ufw is
    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
2026-11-04 Document the console, tools, installer and doctor; add them to the checks
    docs/TESTING.md gains the serial console with an example `diag` output, the
    direct sensor probe, raw captures with decode_capture.py, the uConsole
    installer and doctor flow, a section on analyzing logs and recordings, and a
    mermaid triage flowchart; the expected RD-03D rate is corrected to 10 frames/s
    (the datasheet's report rate) and the LD19 PWM pin is tied to GND as the 2022
    development manual requires. The calibration notes explain the RD-03D mounting
    posture (44 mm axis vertical, connector end down; its +/-60 degree fan opens
    across the 15 mm width) and the LD19's zero direction through its rear ear.
    README.md: r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
2026-11-06 Correct README facts from the datasheet research and add pyserial to the installer
    The charger module is a TP4056 (no source knows a "BW4056"); a 103450 pouch
    holds 1800-2000 mAh, so the 3000 mAh recommendation now names a 606090; the
    uConsole section describes the official CM4 image v3.1 (Raspberry Pi OS
    Trixie, labwc, NetworkManager, pygame/numpy/pyserial preinstalled, XDG
    autostart honoured) and how to make the 4G module permanent and give it a
    NetworkManager GSM connection. The installer adds python3-serial so
    tools/sensor_probe.py works out of the box.
    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
2026-11-06 Rebuild the Level 2 enclosure from the manufacturers' drawings
    The previous draft guessed the LD19 hole pattern and laid the RD-03D on its
    side. The LD19 datasheet drawing and two STEP models give three mounting ears
    with Ø2.5 holes at (±23.40, +8.52) and (0, −23.40) from the rotation axis and
    Ø4.46 × 2 mm counterbores underneath; the Ai-Thinker manual shows that the
    radar's ±60° azimuth field opens across the board's 15 mm width, so the board
    must stand upright with its connector end down.
    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
2026-11-06 Fix defects found by the adversarial review of the bring-up tooling
    Firmware: the USB CDC transmit ring defaults to 256 bytes and, with the 0 ms
    TX timeout, a line that does not fit is dropped rather than queued, so a raw
    dump (four 108-byte lines per loop pass) and a multi-line diag reply lost
    whole lines. The ring is now SERIAL_TX_BUFFER (4096) bytes and the dump
    prints a line only when availableForWrite() has room for it. The raw capture
    deadline is derived from the requested byte count (the radar streams only 300
    bytes/s, so any request over 3000 bytes timed out and was reported as a silent
    UART); a timeout now says "silent" only when nothing at all arrived. Before
    ESP.restart() the TX t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
2026-11-06 Fix the installer and doctor defects found by the review; align wording
    install.sh: the relay unit and its token file are installed through root
    (install -D), so --relay no longer dies with "Permission denied" as a normal
    user; under sudo the login user's home is resolved from the password database
    and the autostart entry and data directory are created owned by that user
    instead of root; Desktop Entry Exec= and systemd ExecStart=/WorkingDirectory=
    arguments are quoted and escaped, so a repository path with a space or a token
    with $ or % works; the web token is written to /etc/radarlink/relay.env (mode
    0600) and read by the relay from RADAR_WEB_TOKEN rather than passed on the
    command line whe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
